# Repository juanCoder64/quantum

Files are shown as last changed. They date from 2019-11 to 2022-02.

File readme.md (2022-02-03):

# ejemplos
 ## [brujula](https://github.com/juanCoder64/quantum/tree/master/Ejemplos/brujula)
### Que hace
 Orienta el robot hacia el lugar donde empezó
### librerías necesarias
 * [Movimiento](https://github.com/juanCoder64/quantum/tree/master/Bibliotecas/Movimiento)
 * Wire
 * Adafruit_Sensor
 * Adafruit_BNO055
 * Adafruit_GFX
 * Adafruit_SSD1306
 ## [buscar_pelota](https://github.com/juanCoder64/quantum/tree/master/Ejemplos/buscar_pelota)
  ### Que hace
   Busca la pelota usando los sensores IR y luego la sigue.
  ### librerías necesarias:
   * [IR360](https://github.com/juanCoder64/quantum/tree/master/Bibliotecas/IR360)
   * Wire
   * Adafruit_Sensor
   * Adafruit_BNO055
   * Adafruit_SSD1306
   * Adafruit_GFX
   * HTInfraredSeeker
   * [Movimiento](https://github.com/juanCoder64/quantum/tree/master/Bibliotecas/Movimiento)

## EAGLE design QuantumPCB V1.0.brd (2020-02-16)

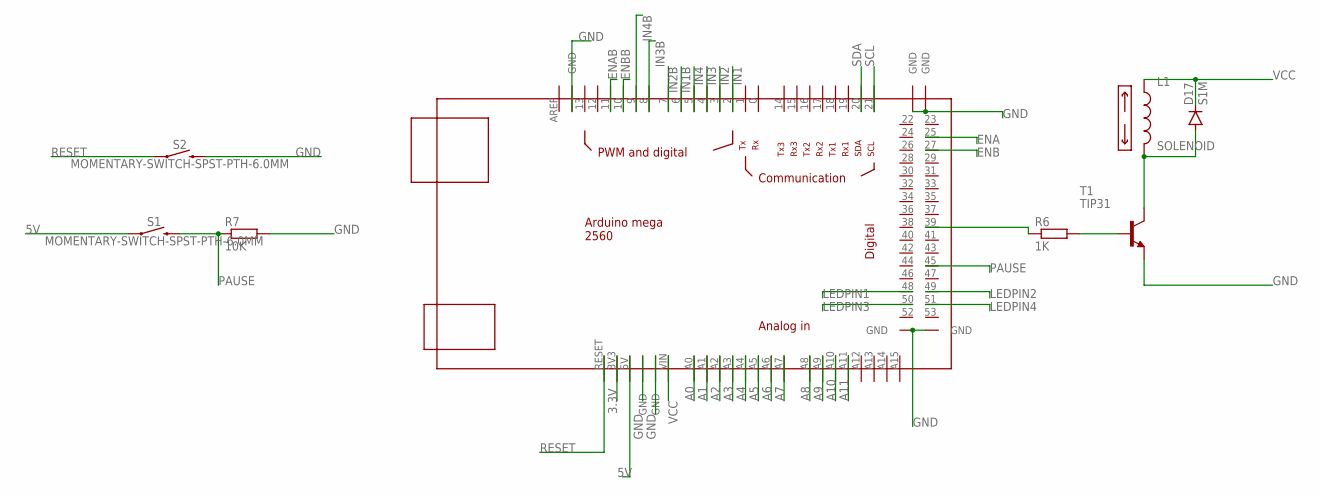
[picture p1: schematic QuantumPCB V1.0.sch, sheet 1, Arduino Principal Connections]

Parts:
D17: S1M; SMA
L1: SOLENOID; 1X02
R6: 1K; R0603
R7: 10K; R0603
S1, S2: MOMENTARY-SWITCH-SPST-PTH-6.0MM; TACTILE_SWITCH_PTH_6.0MM
T1: TIP31; TO220
U$1: MEGA_DEVICE; MEGAOUTLINE

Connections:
3.3V: U$1.3V3; also elsewhere on the board
5V: S1.1, U$1.5V; also elsewhere on the board
A0: U$1.A0; also elsewhere on the board
A1: U$1.A1; also elsewhere on the board
A2: U$1.A2; also elsewhere on the board
A3: U$1.A3; also elsewhere on the board
A4: U$1.A4; also elsewhere on the board
A5: U$1.A5; also elsewhere on the board
A6: U$1.A6; also elsewhere on the board
A7: U$1.A7; also elsewhere on the board
A8: U$1.A8; also elsewhere on the board
A9: U$1.A9; also elsewhere on the board
A10: U$1.A10; also elsewhere on the board
A11: U$1.A11; also elsewhere on the board
ENA: U$1.25; also elsewhere on the board
ENAB: U$1.11; also elsewhere on the board
ENB: U$1.27; also elsewhere on the board
ENBB: U$1.10; also elsewhere on the board
GND: R7.2, S2.3 (2), T1.3 (E), U$1.GND@1 (GND), U$1.GND@2 (GND), U$1.GND@3 (GND), U$1.GND@4 (GND), U$1.GND@5 (GND), U$1.GND@6 (GND), U$1.GND@7 (GND); also elsewhere on the board
IN1: U$1.2; also elsewhere on the board
IN1B: U$1.6; also elsewhere on the board
IN2: U$1.3; also elsewhere on the board
IN2B: U$1.7; also elsewhere on the board
IN3: U$1.4; also elsewhere on the board
IN3B: U$1.8; also elsewhere on the board
IN4: U$1.5; also elsewhere on the board
IN4B: U$1.9; also elsewhere on the board
LEDPIN1: U$1.48; also elsewhere on the board
LEDPIN2: U$1.49; also elsewhere on the board
LEDPIN3: U$1.50; also elsewhere on the board
LEDPIN4: U$1.51; also elsewhere on the board
unnamed: R6.1, U$1.39
unnamed: R6.2, T1.1 (B)
unnamed: D17.A, L1.2, T1.2 (C)
PAUSE: R7.1, S1.3 (2), U$1.45
RESET: S2.1, U$1.RESET
SCL: U$1.21; also elsewhere on the board
SDA: U$1.20; also elsewhere on the board
VCC: D17.C, L1.1, U$1.VIN; also elsewhere on the board

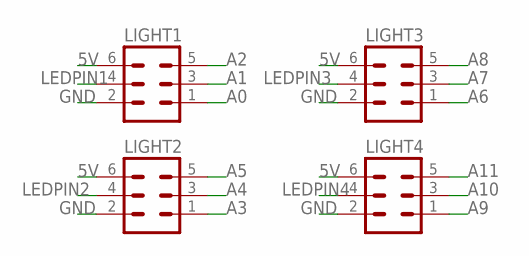
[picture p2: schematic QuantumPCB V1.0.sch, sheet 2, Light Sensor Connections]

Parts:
LIGHT1, LIGHT2, LIGHT3, LIGHT4: MA03-2

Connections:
5V: LIGHT1.6, LIGHT2.6, LIGHT3.6, LIGHT4.6; also elsewhere on the board
A0: LIGHT1.1; also elsewhere on the board
A1: LIGHT1.3; also elsewhere on the board
A2: LIGHT1.5; also elsewhere on the board
A3: LIGHT2.1; also elsewhere on the board
A4: LIGHT2.3; also elsewhere on the board
A5: LIGHT2.5; also elsewhere on the board
A6: LIGHT3.1; also elsewhere on the board
A7: LIGHT3.3; also elsewhere on the board
A8: LIGHT3.5; also elsewhere on the board
A9: LIGHT4.1; also elsewhere on the board
A10: LIGHT4.3; also elsewhere on the board
A11: LIGHT4.5; also elsewhere on the board
GND: LIGHT1.2, LIGHT2.2, LIGHT3.2, LIGHT4.2; also elsewhere on the board
LEDPIN1: LIGHT1.4; also elsewhere on the board
LEDPIN2: LIGHT2.4; also elsewhere on the board
LEDPIN3: LIGHT3.4; also elsewhere on the board
LEDPIN4: LIGHT4.4; also elsewhere on the board

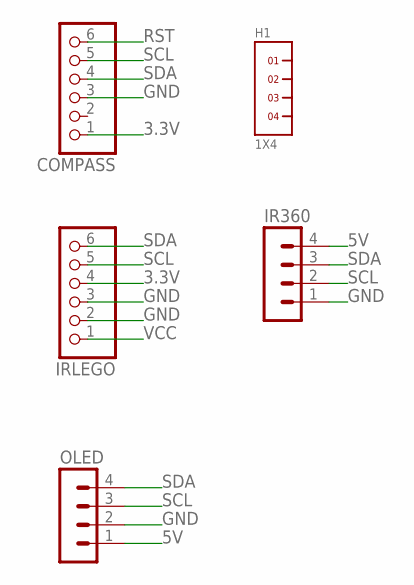
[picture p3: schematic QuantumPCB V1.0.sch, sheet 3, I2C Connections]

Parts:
COMPASS: PINHD-1X6; 1X06
H1: 1X4
IR360: MA04-1
IRLEGO: PINHD-1X6; 1X06
OLED: MA04-1

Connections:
3.3V: COMPASS.1, IRLEGO.4; also elsewhere on the board
5V: IR360.4, OLED.1; also elsewhere on the board
GND: COMPASS.3, IR360.1, IRLEGO.2, IRLEGO.3, OLED.2; also elsewhere on the board
RST: COMPASS.6
SCL: COMPASS.5, IR360.2, IRLEGO.5, OLED.3; also elsewhere on the board
SDA: COMPASS.4, IR360.3, IRLEGO.6, OLED.4; also elsewhere on the board
VCC: IRLEGO.1; also elsewhere on the board

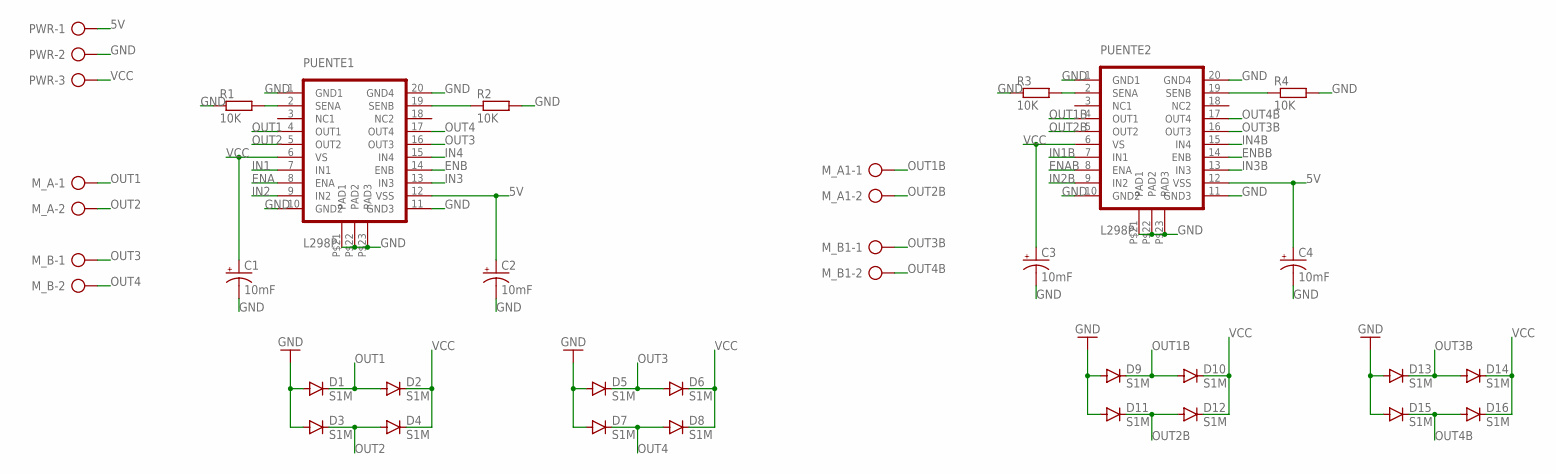
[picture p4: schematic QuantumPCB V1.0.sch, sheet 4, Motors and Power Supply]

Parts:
C1, C2, C3, C4: 10mF; E2-5
D1, D2, D3, D4, D5, D6, D7, D8, D9, D10, D11, D12, D13, D14, D15, D16: S1M; SMA
M_A, M_A1: AK500/2
M_B, M_B1: AK500/2
PUENTE1, PUENTE2: L298P; POWER-SO20
PWR: AK500/3
R1, R2, R3, R4: 10K; R0603

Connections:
5V: C2.+, C4.+, PUENTE1.P$12 (VSS), PUENTE2.P$12 (VSS), PWR.1; also elsewhere on the board
ENA: PUENTE1.P$8 (ENA); also elsewhere on the board
ENAB: PUENTE2.P$8 (ENA); also elsewhere on the board
ENB: PUENTE1.P$14 (ENB); also elsewhere on the board
ENBB: PUENTE2.P$14 (ENB); also elsewhere on the board
GND: C1.-, C2.-, C3.-, C4.-, D1.A, D3.A, D5.A, D7.A, D9.A, D11.A, D13.A, D15.A, PUENTE1.P$1 (GND1), PUENTE1.P$10 (GND2), PUENTE1.P$11 (GND3), PUENTE1.P$20 (GND4), PUENTE1.P$21 (PAD1), PUENTE1.P$22 (PAD2), PUENTE1.P$23 (PAD3), PUENTE2.P$1 (GND1), PUENTE2.P$10 (GND2), PUENTE2.P$11 (GND3), PUENTE2.P$20 (GND4), PUENTE2.P$21 (PAD1), PUENTE2.P$22 (PAD2), PUENTE2.P$23 (PAD3), PWR.2, R1.1, R2.2, R3.1, R4.2; also elsewhere on the board
IN1: PUENTE1.P$7 (IN1); also elsewhere on the board
IN1B: PUENTE2.P$7 (IN1); also elsewhere on the board
IN2: PUENTE1.P$9 (IN2); also elsewhere on the board
IN2B: PUENTE2.P$9 (IN2); also elsewhere on the board
IN3: PUENTE1.P$13 (IN3); also elsewhere on the board
IN3B: PUENTE2.P$13 (IN3); also elsewhere on the board
IN4: PUENTE1.P$15 (IN4); also elsewhere on the board
IN4B: PUENTE2.P$15 (IN4); also elsewhere on the board
unnamed: PUENTE1.P$2 (SENA), R1.2
unnamed: PUENTE1.P$19 (SENB), R2.1
unnamed: PUENTE2.P$2 (SENA), R3.2
unnamed: PUENTE2.P$19 (SENB), R4.1
OUT1: D1.C, D2.A, M_A.1, PUENTE1.P$4 (OUT1)
OUT1B: D9.C, D10.A, M_A1.1, PUENTE2.P$4 (OUT1)
OUT2: D3.C, D4.A, M_A.2, PUENTE1.P$5 (OUT2)
OUT2B: D11.C, D12.A, M_A1.2, PUENTE2.P$5 (OUT2)
OUT3: D5.C, D6.A, M_B.1, PUENTE1.P$16 (OUT3)
OUT3B: D13.C, D14.A, M_B1.1, PUENTE2.P$16 (OUT3)
OUT4: D7.C, D8.A, M_B.2, PUENTE1.P$17 (OUT4)
OUT4B: D15.C, D16.A, M_B1.2, PUENTE2.P$17 (OUT4)
VCC: C1.+, C3.+, D2.C, D4.C, D6.C, D8.C, D10.C, D12.C, D14.C, D16.C, PUENTE1.P$6 (VS), PUENTE2.P$6 (VS), PWR.3; also elsewhere on the board

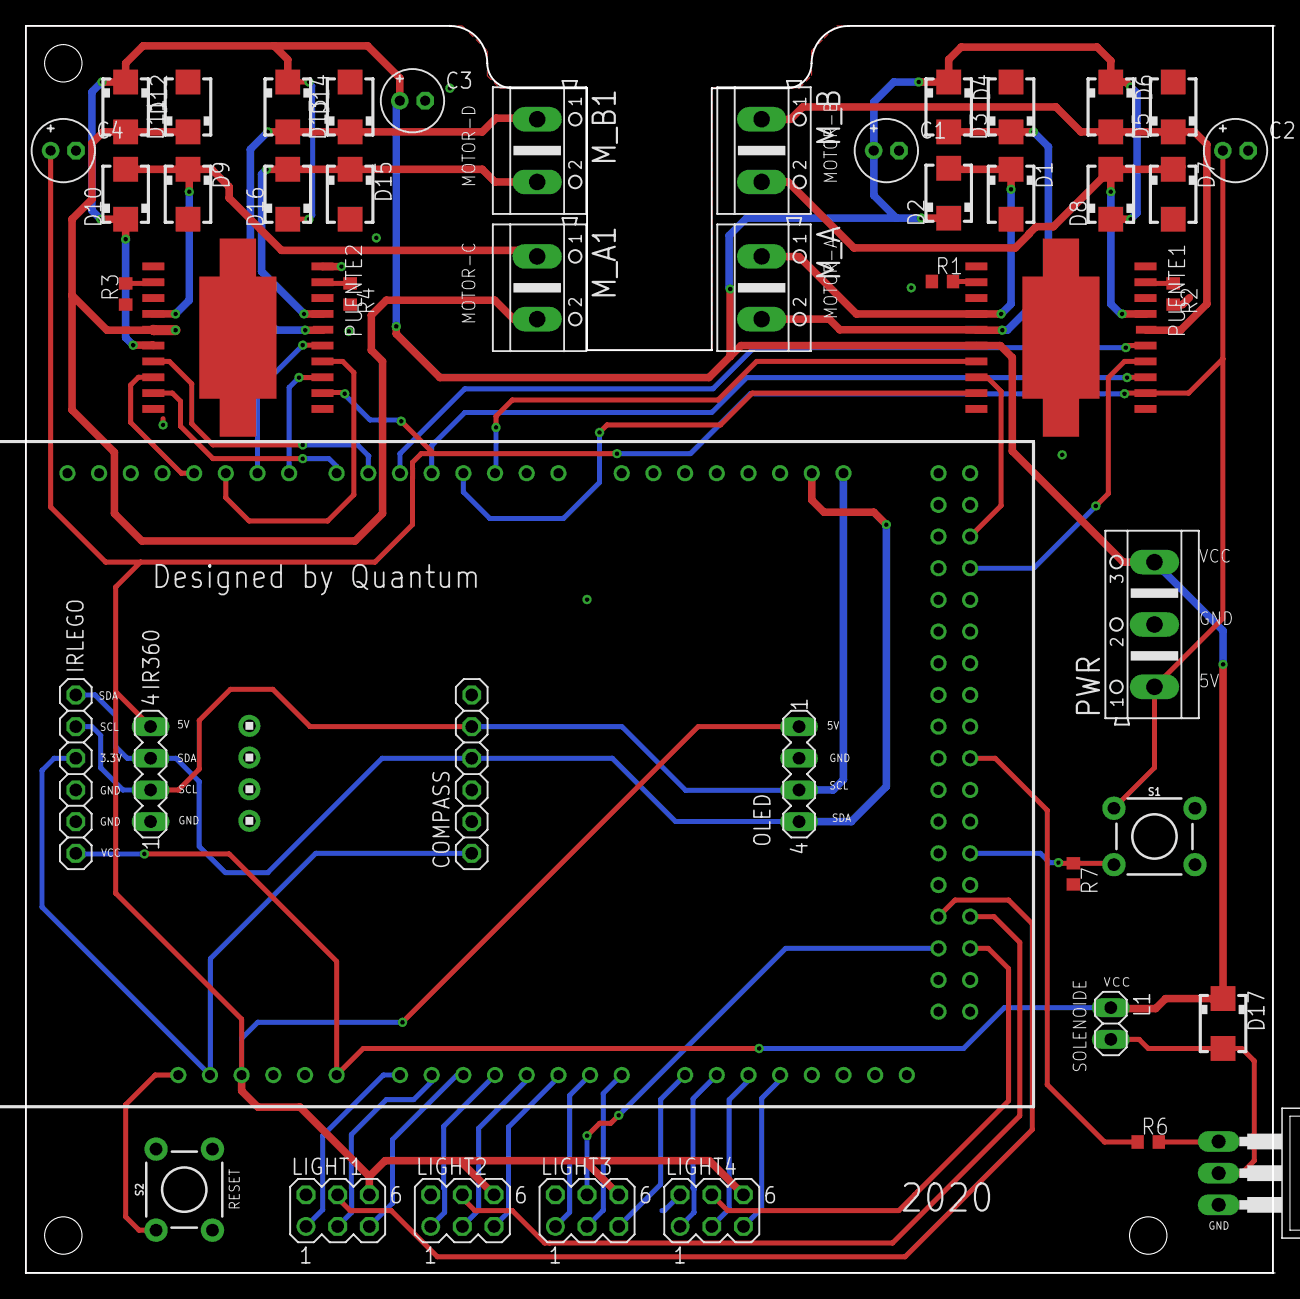
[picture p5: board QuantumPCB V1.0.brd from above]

Board: 2 copper layers, 100.0 x 100.0 mm, 48 parts (0 on the bottom side), 51 nets.

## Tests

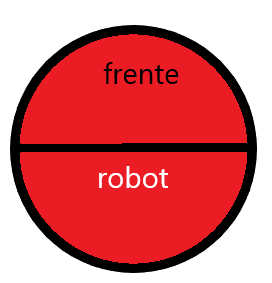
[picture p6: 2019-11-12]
Pruebas/prueba grafica del robot/codigo/application.windows32/robot.png

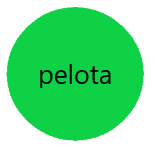
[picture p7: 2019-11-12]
Pruebas/prueba grafica del robot/codigo/pelota.png

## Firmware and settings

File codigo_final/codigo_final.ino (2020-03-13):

/*
    Código del equipo Chabots Quantum -[:] para el torneo mexicano de robotica 2020
    este y otros códigos más se pueden encontrar en https://github.com/juanCoder64/quantum
*/
#include "evitarLinea.h"
#include "buscar_pelota.h"
#include "orientacion.h"
orientacion orientation;
evitarLinea linea;
pelota IR;
void setup() {
  IR.Begin();
  linea.calibrar();
}
void loop() {
  if (orientation.frente()) {
    if (!linea.linea()) {
      IR.run();
    }
    else {
      linea.run();
    }
  }
  else {
    orientation.run();
  }
}

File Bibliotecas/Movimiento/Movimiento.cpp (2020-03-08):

#include "Arduino.h"
#include "Movimiento.h"
Movimiento::Movimiento(float KP,float KI, float KD) {
  //motor B
  pinMode(2, OUTPUT);
  pinMode(3, OUTPUT);
  pinMode(25, OUTPUT);
  digitalWrite(25, HIGH);
  //motor A
  pinMode(4, OUTPUT);
  pinMode(5, OUTPUT);
  pinMode(27, OUTPUT);
  digitalWrite(27, HIGH);
  //motor D
  pinMode(6, OUTPUT);
  pinMode(7, OUTPUT);
  pinMode(11, OUTPUT);
  digitalWrite(11, HIGH);
  //motor C
  pinMode(8, OUTPUT);
  pinMode(9, OUTPUT);
  pinMode(10, OUTPUT);
  digitalWrite(10, HIGH);
  kP = KP;
  kI = KI;
  kD = KD;
}
void Movimiento::muevete(int ANGLE, int MAXSpeed, float brujula) {
  P = 0 - brujula;
  error = P;
  errorSum += error;
  I = 0-errorSum;
  D = errorPrev-error;
  P *= KP;
  I *= KI;
  D *= KD;
  errorPrev=error;
  PID = P+I+D;
  a = sin(((PID + ANGLE + 135) * PI) / 180) * MAXSpeed;
  b = sin(((PID + ANGLE + 45) * PI) / 180) * MAXSpeed;
  c = sin(((PID + ANGLE + 315) * PI) / 180) * MAXSpeed;
  d = sin(((PID + ANGLE + 225) * PI) / 180) * MAXSpeed;
  a = constrain(a, -255, 255);
  b = constrain(b, -255, 255);
  c = constrain(c, -255, 255);
  d = constrain(d, -255, 255);
  if (a < 0) {
    analogWrite(2, LOW);
    analogWrite(3, -a);
    a = -a;
  }
  else {
    analogWrite(2, a);
    analogWrite(3, LOW);

  }
  //----------------
  if (b < 0) {
    analogWrite(4, LOW);
    analogWrite(5, -b);
    b = -b;
  }
  else {
    analogWrite(4, b);
    analogWrite(5, LOW);
  }
  if (c < 0) {
    analogWrite(6, LOW);
    analogWrite(7, -c);
    c = -c;
  }
  else {
    analogWrite(6, c);
    analogWrite(7, LOW);

  }
  if (d < 0) {
    analogWrite(8, LOW);
    analogWrite(9, -d);
    d = -d;
  }
  else {
    analogWrite(8, d);
    analogWrite(9, LOW);
  }
	Serial.println(a);
	Serial.println("\t");
	Serial.println(b);
	Serial.println("\t");
	Serial.println(c);
	Serial.println("\t");
	Serial.println(d);

}
void Movimiento::rota(int brujula) {
  if (brujula < 180) {
  	P = map(brujula, 10, 180, 30, 200);
    PID =P+I+D;
    analogWrite(2, PID);
    analogWrite(3, LOW);
    analogWrite(4, PID);
    analogWrite(5, LOW);
    analogWrite(6, PID);
    analogWrite(7, LOW);
    analogWrite(8, PID);
    analogWrite(9, LOW);
  }
  else {
  	P = map(brujula, 180, 350, 200, 30);
  	PID =P+I+D;
    analogWrite(2, LOW);
    analogWrite(3, PID);
    analogWrite(4, LOW);
    analogWrite(5, PID);
    analogWrite(6, LOW);
    analogWrite(7, PID);
    analogWrite(8, LOW);
    analogWrite(9, PID);
  }
}

void Movimiento::recio() {
  analogWrite(2, HIGH);
  analogWrite(3, HIGH);
  analogWrite(4, HIGH);
  analogWrite(5, HIGH);
  analogWrite(6, HIGH);
  analogWrite(7, HIGH);
  analogWrite(8, HIGH);
  analogWrite(9, HIGH);
}

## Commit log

2019-09-01 Create readme.md
    aqui va todo lo que llevamos
2019-09-19 arreglar el bug de la calibración
2019-11-12 algunos cambios son experimentales
    [serialconfig.txt]
2019-11-12 chaBots -[:] Quantum֍
2019-11-12 Auto stash before rebase of "refs/heads/master"
    [serialconfig.txt]
2019-11-12 Chabots Quantum -[:]
    -[:]
    [serialconfig.txt]
2019-11-17 Chabots Quenatum -[:]
    [serialconfig.txt]
2019-11-18 versión 2.0
    se añaden motores
2019-12-04 sensor color
2019-12-22 mejoras en librería
    en la vuelta solo tiene proporcional
2019-12-27 corrección PID
2020-02-16 reparacion de libreria de moviniemto
2020-03-08 seguir la pelota con los 2 sensores

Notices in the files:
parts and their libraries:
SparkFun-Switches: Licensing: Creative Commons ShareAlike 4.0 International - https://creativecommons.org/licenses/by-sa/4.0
